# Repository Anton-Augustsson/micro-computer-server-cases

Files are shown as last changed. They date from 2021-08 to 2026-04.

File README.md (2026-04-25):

# Micro Computer Server Cases
3D printed server rack node cases is made for mounting Raspberry Pi, SSD, external hard drives, and more.

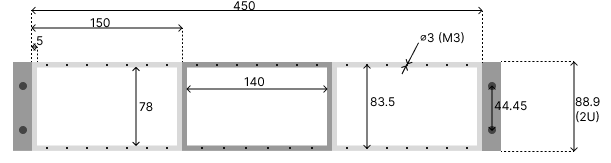
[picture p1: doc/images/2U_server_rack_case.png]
2U server rack case


## Terminology
- Server rack node case: is the case you can mount on a 19" server rack, comprised of 3 cases to simplify printing.
- Side case: the case that has the mounting holes for the 19" server rack.
- Middle case: the case that connect the left and right side.
- Node: e.g., Raspberry Pi, SSD, external hard drives, etc.
- Node holder: what a node is mounted to fit in a case.
- Case inter height: the inside vertical dimension of the case. This is the maximum allowed width of a node.
- Case inter width: the inside horizontal dimension of the case.
- Case outer height: is the same as 1U, 2U, etc.
- Case outer width: is not the total width of a case instead it's using a standardized side thickness.
- Node hole vertical distance: is the distance between the bottom node mounting hole to the top mounting hole.
- Node hole horizontal distance: is the distance between the one node mounting hole to the next.
- Horizontal wall thickness: the thickness of the case bottom and top walls.
- Vertical wall thickness: the thickness of the left and right side walls.
- Case depth thickness: how deep the case is. This must be more than the threaded inserts.

## Standard size
### Raspberry pi
- [All models](https://www.raspberrypi.org/documentation/hardware/raspberrypi/mechanical/README.md)
- [pi 4](https://www.raspberrypi.org/documentation/hardware/raspberrypi/mechanical/rpi_MECH_4b_4p0.pdf)
- [pi 3b+](https://www.raspberrypi.org/documentation/hardware/raspberrypi/mechanical/rpi_MECH_3bplus.pdf)

### Hard drive
- [HDD 3.5](https://www.overclock.net/photopost/data/823390/1/1a/1aec7c11_3_5_emount.jpeg)
- [SSD](https://www.intel.com/content/www/us/en/support/articles/000006346/memory-and-storage.html)

### Server case
- [Rack dimensions](https://upload.wikimedia.org/wikipedia/commons/thumb/0/08/19_inch_rack_dimensions.svg/767px-19_inch_rack_dimensions.svg.png)
- [EIA Standard](https://www.ibm.com/docs/en/n-series?topic=specifications-requirements)

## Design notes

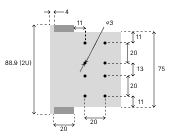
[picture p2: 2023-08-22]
doc/images/Horizontal_node_case_side_profile.png

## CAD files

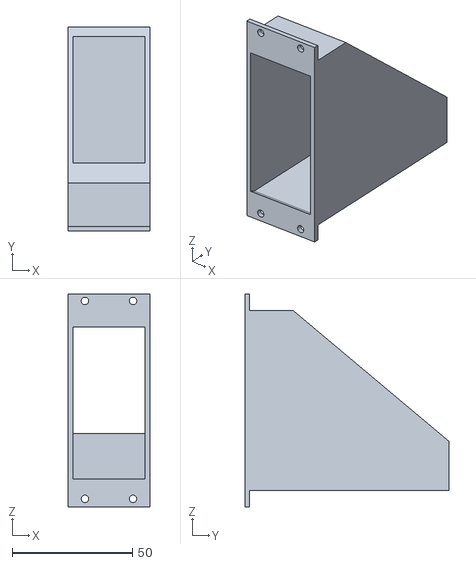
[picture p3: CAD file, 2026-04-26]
stl/linocell-premium-gan-multiladdare-pd-3-0-100-w-holder.stl
34.0 x 85.0 x 88.6

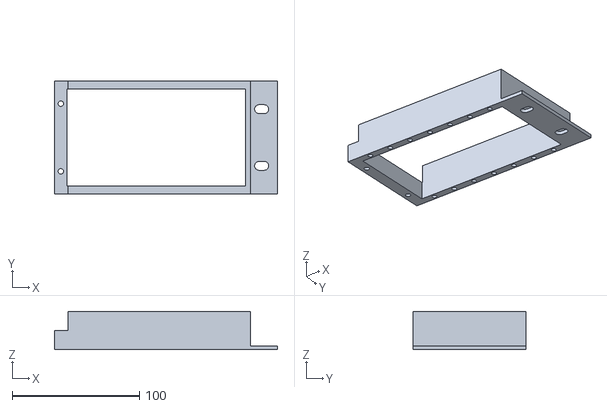
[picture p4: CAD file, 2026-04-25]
stl/2u-case-side.stl
175.0 x 88.6 x 30.0

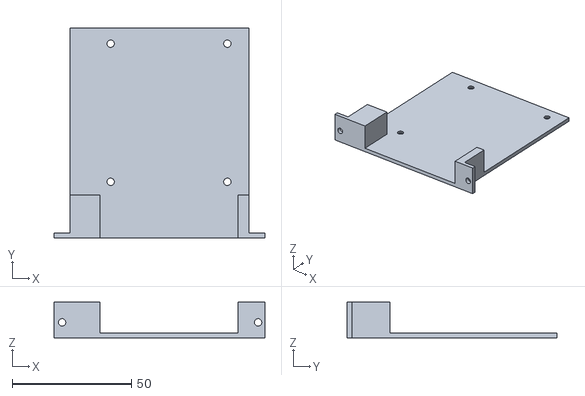
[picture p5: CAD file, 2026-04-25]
stl/raspberry-pi-4-model-b-holder.stl
88.6 x 88.0 x 15.0

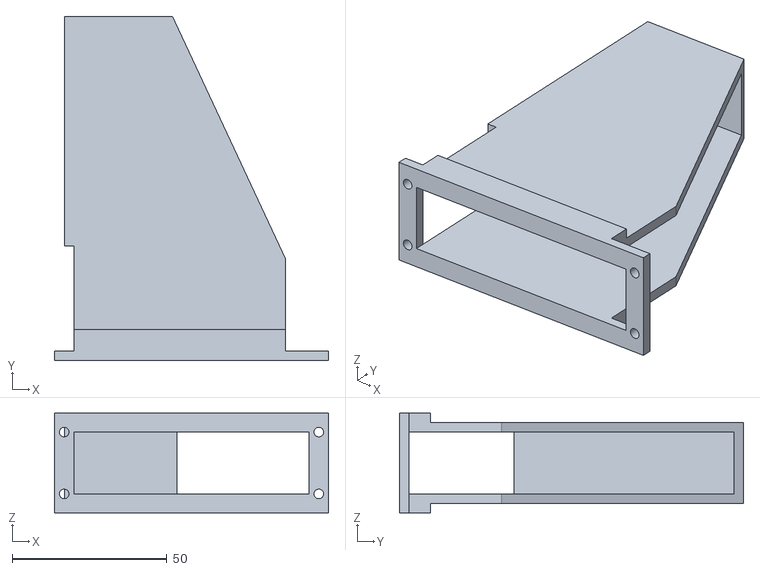
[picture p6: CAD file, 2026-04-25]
stl/wd-my-passport-holder.stl
88.6 x 111.2 x 32.2

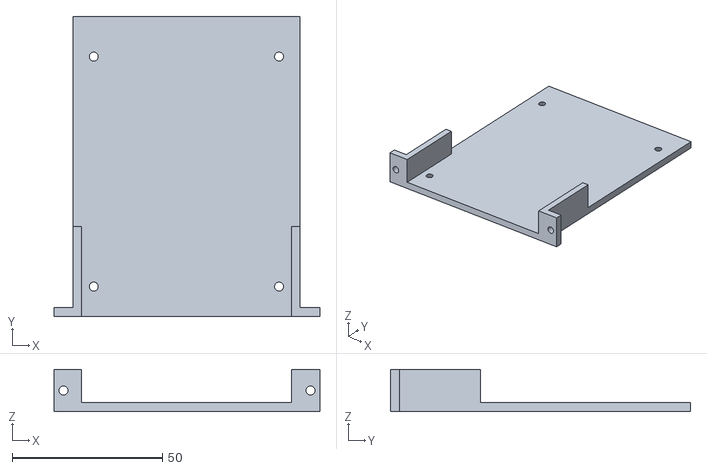
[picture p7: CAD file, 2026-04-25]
stl/ssd-holder.stl
88.6 x 100.0 x 14.0

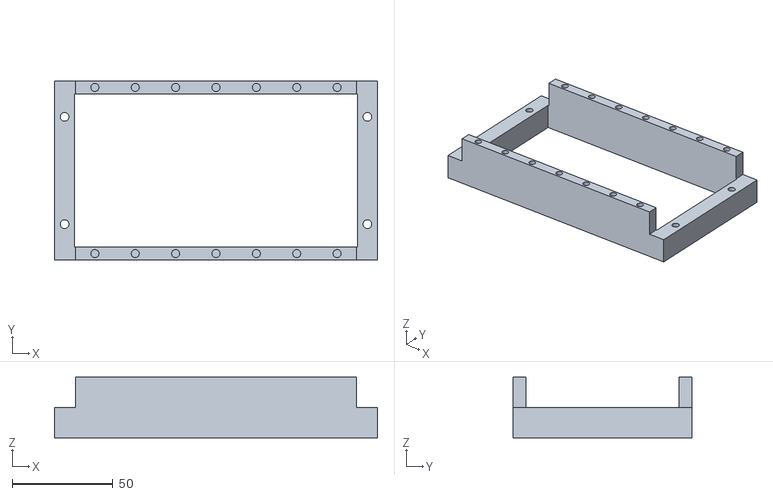
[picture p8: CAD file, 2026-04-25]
stl/2u-case-middle.stl
160.0 x 88.6 x 30.0

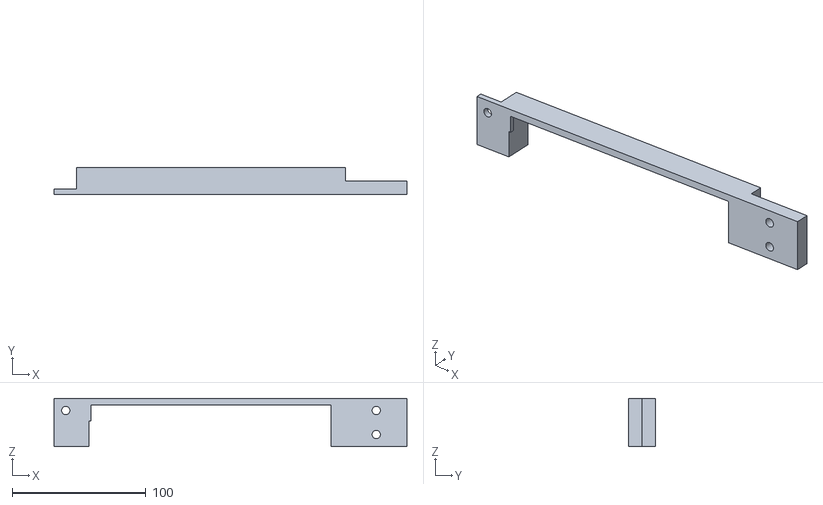
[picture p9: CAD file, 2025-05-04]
stl/usff7040L.stl
264.3 x 20.0 x 36.0

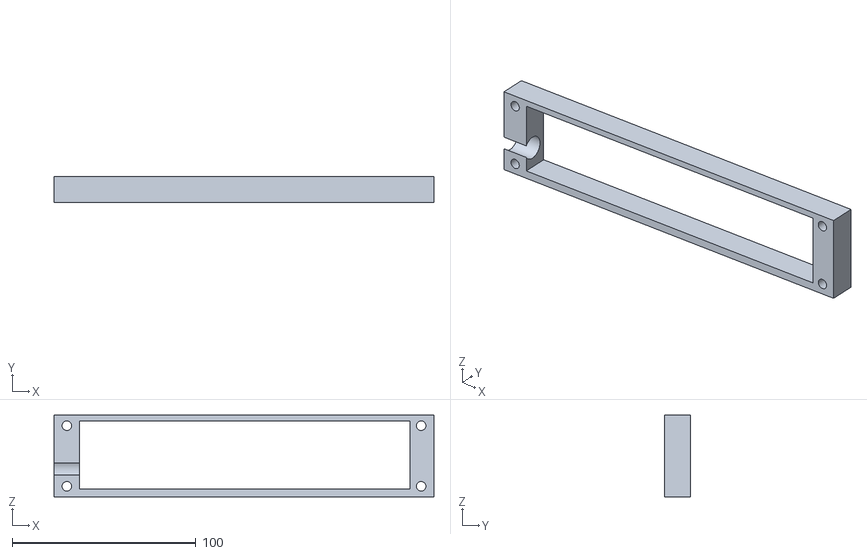
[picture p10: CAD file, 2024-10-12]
stl/usff-pc-side.stl
207.0 x 14.0 x 44.5

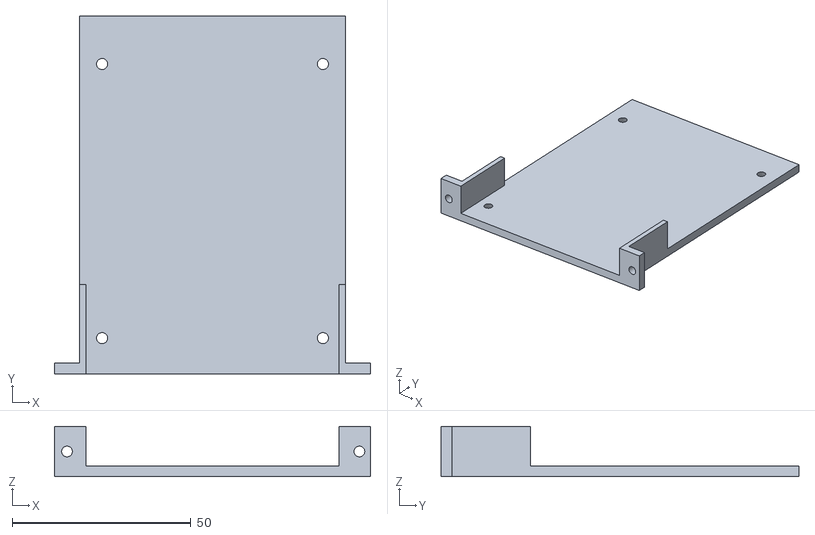
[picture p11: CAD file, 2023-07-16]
stl/ssd.stl
88.3 x 100.0 x 14.0

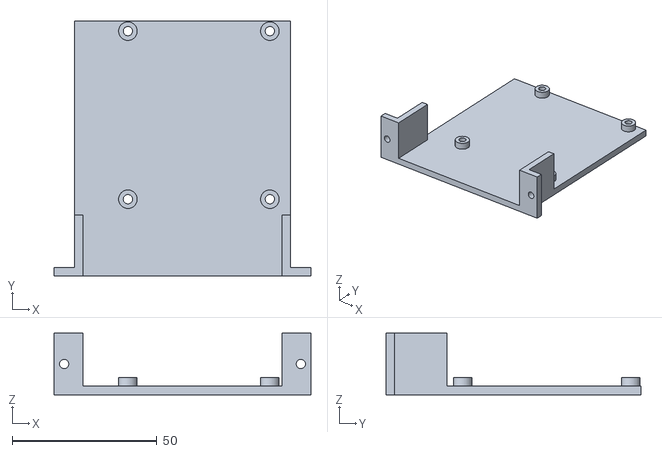
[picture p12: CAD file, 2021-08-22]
stl/pimount.stl
88.7 x 88.0 x 21.3

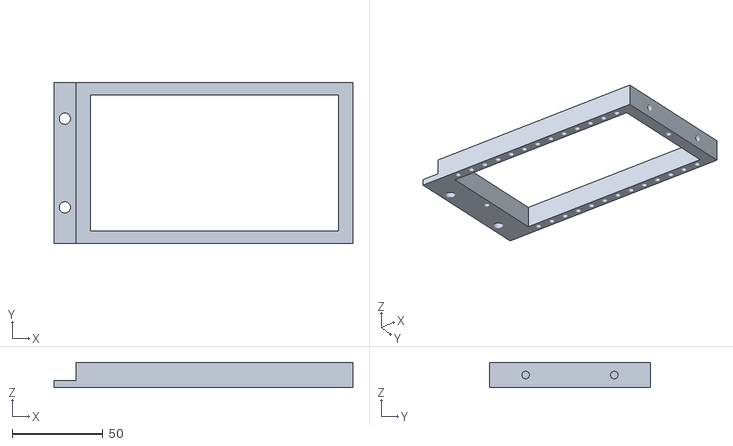
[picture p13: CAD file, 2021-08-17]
stl/mc-server-case.stl
164.9 x 88.9 x 14.0

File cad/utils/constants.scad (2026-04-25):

$fn=90;  // accuracy

/* Server dimentions */

// one server unit
c_1u = 44.45;  

// two server unit
c_2u = c_1u*2; // 88.9

// total width
// The total with of the a server rack (19")
// this includes the mounting holes
c_tw  = 482.6; 

// Total inner width
// The distance between the mounting holes in the server rack
c_tiw = 450;


/* Rack hole dimentions */

// width distance rack holes
c_wdrh = 465;

// height distance rack holes
c_hdrh = 33;


/* dell optiplex 7040 micro usff dimentions */

// dell optiplex 7040 height
c_do7040h = 36;

// dell optiplex 7040 width
c_do7040w = 182;

// dell optiplex 7040 depth
c_do7040d = 179;

// dell optiplex 7040 rubber feet width distance
c_do7040rfwd = 14.9;

// dell optiplex 7040 rubber feet back depth distance
c_do7040rfbdd = 9.9;


/* Case dimentions */

// case height outer 
// A small margin is included to so that the case does not 
// exide two server units
c_2ucho = 88.6; 

// case height inner
// The thickness of the walls can then be calculated as (cho-chi)/2
c_2uchi = 76;

// distance between node holes
c_2udbnh = 82.3;

// case width outer
// as there are three parts of the rack server case we just devide
// the total inner width with three 
c_cwo = c_tiw/3; // 150

// case width inner
// Needs to be less than case width outer
c_cwi = 140;

// case depth thickness
// How thick the case should be. It needs to be thicker than the hight
// of the threaded insert.
c_cdt = 30;

// case inner side thickness
// The middle and the side case over lap so that a screw can be entered
// between the two cases. The cist is defined as the thickness of the part
// that does not overlap between the midle and side case.
c_cist = 3.5;

// nodes per case
c_npc = 7;

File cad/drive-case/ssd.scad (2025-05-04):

include <../utils/constants.scad>;

/* ssdMount
    Mount for ssd to be installed on
    micro-computer-server-case
    
    chi: case height inner
    cho: case height outer
    nw:  node width
*/
module ssdMount(chi,cho,nw){
    ct = (cho-chi)/2; // case thickness
    nmt = 3; // node mouting thickness
    chim = chi-0.4; // case height - margin

    w = 69.9; // width sdd
    d = 100; // depth ssd
   
    dbhd = 76.6; // distance between holes depth
    dbhw = 61.72; // distance between holes width
   
    hd = 3; // hole diameter
    hde = hd+3;// hole diameter extra
   
    s=0.1;
    s2=s*2; 
   
    module ssdHole(x,y){
        translate([x,y,-0.1])
        cylinder(h=nmt+0.2,d2=hd,d1=hde);
    }
    module mountHole(x){
        translate([x,nmt/2,nw/2])
        rotate([90,0,0])
        cylinder(h=nmt+s2,d=hd,center=true);

    } 

    difference(){
        union(){
            cube([chim,d,nmt]); // Base plate

            translate([-ct,0,0])
            cube([ct,nmt,nw]); // For mount to case

            translate([chim,0,0])
            cube([ct,nmt,nw]); // For mount to case

            // TODO: remove, just for development
            //translate([(chim-w)/2,0,nmt])
            //#cube([w,d,10]); // For mount to case

            cube([(chim-w)/2-0.4,d/4,nw]); // For mount to case
            translate([chim-((chim-w)/2-0.4),0,0])
            cube([(chim-w)/2-0.4,d/4,nw]); // For mount to case
        }
        union(){
            translate([(chim-dbhw)/2,10,0]){
                ssdHole(0,0); // bottom left
                ssdHole(dbhw,0); // bottom right
                ssdHole(0,dbhd); // top left
                ssdHole(dbhw,dbhd); // top right
            }
            mountHole(-ct/2);
            mountHole(cho-ct/2-ct);
        }
   }
}

//u1 = 44.45; // one server unit
//npc = 6;
//tiw = 450-1;  // Total iner width - margin 1
//cwo = tiw/3;
//cwi = cwo-8*2; // Side thinckness is 8

//cho = u1*2-0.2; // two server unit - small margin
//chi = cho-7*2; // Side thinckness is 7
nw = 14; // cwi/npc-2; // -2 for margin

ssdMount(c_chi,c_cho,nw);

//translate([-0.2,0,0])
//#cube([74.8,7,15]);
//translate([-7/2,0,10])
//#cube([81.9,7,5]);

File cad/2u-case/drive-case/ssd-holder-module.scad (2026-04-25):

/* ssdHolder
    Mount for ssd to be installed on
    server rack node case
    
    chi: case height inner
    cho: case height outer
    dbnh: distance between node holes
    cdt: case depth thickness
*/
module ssdHolder(chi,cho,dbnh,cdt){
    hwt = (cho-chi)/2; // horizontal wall thickness
    nhbpt = 3; // node holder base plate thickness
    chim = chi-0.4; // case height inner - margin
    nhw = 14; // node holder width
    nhd = cdt; // node holder depth

    ssdw = 69.9; // sdd width
    ssdd = 100; // ssd depth
   
    dbhd = 76.6; // distance between holes depth
    dbhw = 61.72; // distance between holes width
   
    hd = 3; // hole diameter
    hde = hd+3;// hole diameter extra
   
    module ssdHole(x,y){
        translate([x,y,0])
        cylinder(h=nhbpt,d2=hd,d1=hde);
    }
    module mountHole(x){
        translate([x,nhbpt/2,nhw/2])
        rotate([90,0,0])
        cylinder(h=nhbpt,d=hd,center=true);
    } 

    difference(){
        union(){
            cube([chim,ssdd,nhbpt]); // Base plate

            // For mount to case
            translate([-hwt,0,0])
            cube([cho,nhbpt,nhw]); 
            cube([chim,nhd,nhw]);
        }
        union(){
            // Make space for SSD
            translate([(chim-ssdw)/2,0,nhbpt])
            cube([ssdw,ssdd,nhw]);

            // SSD mount holes
            translate([(chim-dbhw)/2,10,0]){
                ssdHole(0,0); // bottom left
                ssdHole(dbhw,0); // bottom right
                ssdHole(0,dbhd); // top left
                ssdHole(dbhw,dbhd); // top right
            }

            // Mount holes to case
            translate([-hwt/2,0,0]){
              mountHole(0);
              mountHole(dbnh);
            }
        }
   }
}

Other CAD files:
stl/usff7040R.stl
cad/2u-case/drive-case/ssd-holder.scad
cad/1u-case/usff-pc/dell-optiplex-7040/left-7040.scad
cad/1u-case/usff-pc/dell-optiplex-7040/usff7040-for-bottom-of-rack-module.scad
cad/1u-case/usff-pc/dell-optiplex-7040/usff7040-for-bottom-of-rack.scad
cad/1u-case/usff-pc/dell-optiplex-7040/usff7040-module.scad
cad/2u-case/2u-case-middle.scad
cad/2u-case/2u-case-side.scad
cad/2u-case/2u-example.scad
cad/2u-case/drive-case/ssd.scad
cad/2u-case/drive-case/wd-my-passport-holder-module.scad
cad/2u-case/drive-case/wd-my-passport-holder.scad
cad/2u-case/micro-computer-case/raspberry-pi-3-model-b-holder-module.scad
cad/2u-case/micro-computer-case/raspberry-pi-3-model-b-holder.scad
cad/2u-case/micro-computer-case/raspberry-pi-4-model-b-holder-module.scad
cad/2u-case/micro-computer-case/raspberry-pi-4-model-b-holder.scad
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

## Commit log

2020-07-25 hdd mount done
    [hdd-case.scad, hdd-lock.scad, hdd-mount.scad]
2020-07-30 hdd front
    [hdd-front-latch.scad, hdd-front-lock.scad, hdd-front.scad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]
2021-01-15 created a rack case and a mount for ssd
    [mc-server-case.scad]
2021-08-17 added documentation and indentation for case
    [mc-server-case.scad, mc-server-case.stl]
2021-08-17 updated ssd mount
    [mc-server-case.scad]
2021-08-18 Made Rassbary PI case
    [mc-server-case.scad]
2021-08-19 Made a nvidia jetson nano case.
    [mc-server-case.scad]
2021-08-20 Change som mesurmets and added server rack in demo
    [mc-server-case.scad]
2021-08-22 Modefied rack hole position.
    [mc-server-case.scad, pimount.stl]
2023-05-13 simplified version of the server rack case, note mc-server-case cases are now old
    [case-generic.scad, case-middle.scad, case-side.scad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]
2023-05-13 ssd mount
    [ssd.scad]
2023-07-16 cad model for nvidia jetson micro computer
    [jetson.scad]
2023-07-16 ssd and server rack case
    [case-generic.scad, case-middle.scad, case-side.scad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]
2023-08-22 Clean up and created seperate constants file and created horizontal node case
    [case-middle.scad, case-side.scad, constants.scad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]
2024-10-12 started with dell optiplex 7040 1u server case
    [case-side-mount.scad, constants.scad, horizontal-node-case.scad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]
2025-05-04 server case 1.2
    [case-generic.scad, case-middle.scad, case-side.scad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]
2026-02-08 moved into 1u, 2u folders and updated node case to new standard
    [case-generic.scad, case-middle.scad, case-side-mount.scad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]
2026-02-08 moved server rack node case into utils, now acting as a support module
    [2u-case-middle.scad, 2u-case-side.scad, 2u-example.scad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]
2026-02-08 cleanup ssd holder and server rack node case
    [2u-example.scad, case-generic.scad, case-middle.scad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]
2026-04-25 ssd holder, wd my passport and rpi4 holder
    [2u-case-middle.scad, 2u-case-middle.stl, 2u-case-side.scad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]
2026-04-26 Linocell premium GaN multiladdare PD 3.0 100 W
    [linocell-premium-gan-multiladdare-pd-3-0-100-w-holder-module.scad, linocell-premium-gan-multiladdare-pd-3-0-100-w-holder.scad, linocell-premium-gan-multiladdar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]
